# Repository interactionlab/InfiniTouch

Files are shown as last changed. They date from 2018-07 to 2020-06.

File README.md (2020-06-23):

# InfiniTouch: Finger-Aware Interaction on Fully Touch Sensitive Smartphones
This repository contains both the hardware models and specifications for the full-touch smartphone prototype presented in the paper, 
as well as scripts and the model for estimating 3D finger positions on the device as described in the paper. 
Moreover, our dataset can be downloaded in the link provided below.

## Abstract
Smartphones are the most successful mobile devices and offer intuitive interaction through touchscreens. Current devices
treat all fingers equally and only sense touch contacts on the front of the device. In this paper, we present InfiniTouch,
the first system that enables touch input on the whole device surface and identifies the fingers touching the device without
external sensors while keeping the form factor of a standard smartphone. We first developed a prototype with capacitive
sensors on the front, the back and on three sides. We then conducted a study to train a convolutional neural network that
identifies fingers with an accuracy of 95.78% while estimating their position with a mean absolute error of 0.74cm . We
demonstrate the usefulness of multiple use cases made possible with InfiniTouch, including finger-aware gestures and finger
flexion state as an action modifier.

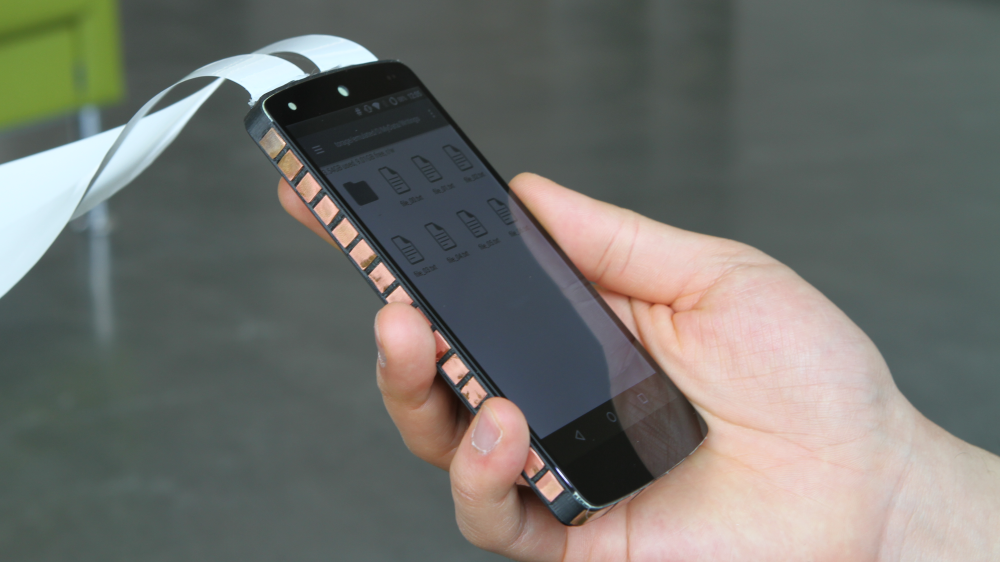
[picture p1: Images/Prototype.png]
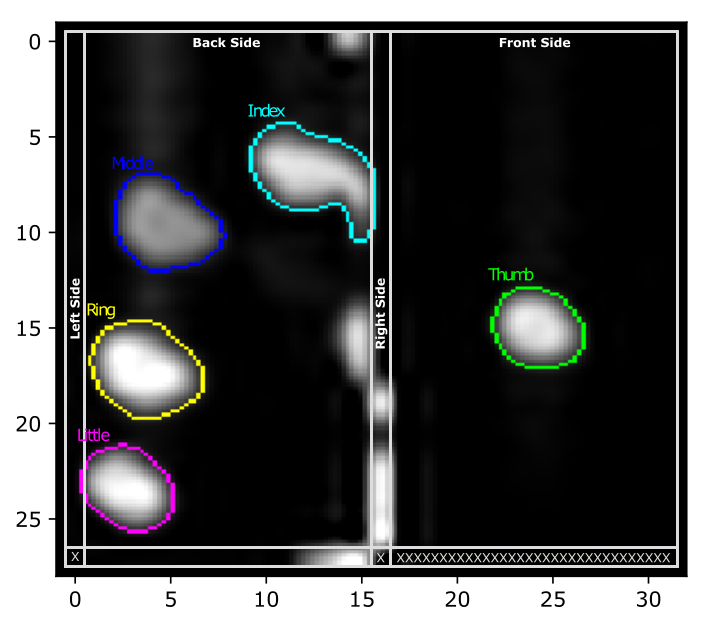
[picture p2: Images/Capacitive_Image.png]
 

This work can be cited as follows:
<pre>
@inproceedings{le2018infinitouch,
 author = {Le, Huy Viet and  Mayer, Sven and Henze, Niels},
 title = {InfiniTouch: Finger-Aware Interaction on Fully Touch Sensitive Smartphones},
 booktitle = {Proceedings of the 31th Annual ACM Symposium on User Interface Software and Technology},
 series = {UIST '18},
 year = {2018},
 isbn = {978-1-4503-5948-1},
 doi = {10.1145/3242587.3242605},
 url = {http://doi.acm.org/10.1145/3242587.3242605},
 location = {Berlin, Germany},
 numpages = {14},
 publisher = {ACM},
 address = {New York, NY, USA}
} 
</pre>

## Dataset
The dataset can be downloaded at: https://www.dropbox.com/s/v8n8uaf5vncusyn/InfiniTouch_Dataset.zip?dl=0. After downloading, place the content of this folder into a folder named 'data'. Place the 'data' folder into the same directory as the Jupyter notebooks. Run the content of these notebooks to create a HDF5 file with which the model can then be trained.

## Prototype
The datasheets of the components that we used in our prototype can be found in the following list of URLs:
- BM10NB(0.8)-40DS-0.4V(51): https://www.datasheets360.com/part/detail/bm10nb-0-8-40ds-0-4v-51/2579290684464631510/
- BM10B(0.8)-40DP-0.4V(51): https://www.datasheets360.com/part/detail/bm10b-0-8-40dp-0-4v-51/-1995328425388918022/
- MPR121QR2: https://www.datasheets360.com/part/detail/mpr121qr2/3714073967749496703/
- MicroUSB Breakout Board: https://cdn-shop.adafruit.com/datasheets/1833_MicroB_20329.pdf
- Tactile Switch: https://cdn-shop.adafruit.com/datasheets/B3F-1000-Omron.pdf
- FH12-50S-0.5SH(05): https://www.datasheets360.com/part/detail/fh12-50s-0-5sh-05/8224149447061018923/
- PCB board + FFC cable: http://diy.shops.hypeltd.com/DIY2//product_info.php?products_id=67

We printed the PCB and placed the components on the board with the service of http://beta-layout.com.

## Android Library
To use the library, include libftsp.jar in your Android project. The capacitive images for the local device can be accessed as follows:
```java
LocalDeviceHandler localDeviceHandler = new LocalDeviceHandler();
localDeviceHandler.setLocalCapImgListener(new LocalCapImgListener() {
    @Override
    public void onLocalCapImg(CapacitiveImageTS capImg) { // called approximately every 50ms
        int[][] matrix = capImg.getMatrix(); // get the 27x15 capacitive image
        int[] flattenedMatrix = capImg.getFlattenedMatrix(); // get a flattened 27x15 capacitive image
        long imgTimestamp = capImg.getTimestamp(); // get timestamp of this image
    }
});
localDeviceHandler.startHandler();
```

The following code is for the front unit. It provides the capacitive images of the front device (local) and further the retrieved capacitive imags of the back and the sides. All capacitive images can be retrieved within callbacks:

```java
try {
    frontDeviceHandler = new FrontDeviceHandler(9584);
} catch (SocketException e) {
    e.printStackTrace();
}

frontDeviceHandler.setFtspCapImgListener(new FTSPCapImgListener() {
    @Override
    public void onNewBackCapacitiveImage(CapacitiveImageTS capacitiveImageTS) {
        // backImage = capacitiveImageTS;
    }

    @Override
    public void onNewFrontCapacitiveImage(CapacitiveImageTS capacitiveImageTS) {
        // frontImage = capacitiveImageTS;
    }

    @Override
    public void onNewSideCapacitiveImage(CapacitiveImageSide capacitiveImageSide) {
        // sideImage = capacitiveImageSide;
    }
});
frontDeviceHandler.startHandler(true);
```

The back unit uses the respective code to broadcast the capacitive images to the front unit. A callback handler can also be added if required.
```java
backDeviceHandler = new BackDeviceHandler(Constants.FRONT_IP, 9584);
backDeviceHandler.startHandler(true);
```

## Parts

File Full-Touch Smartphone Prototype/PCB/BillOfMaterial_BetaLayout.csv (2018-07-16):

BILL OF MATERIAL WITH BETA STOCK, GROUPED BY VALUES, AS OF 09.10.2015
Part | Value | Device | Package | Description | Description2 | Qty | Place_YES/NO | Povided_by_customer_YES/NO | Distributor | Ordernumber | Weblink | Remarks_customer | Unit_price | Total_price | REMARKS_BETA | OPTION1 | OPTION2 | OPTION3
C1, C2, C3, C4, C5, C6 | 0.1uF | CAP0603-CAP | 0603-CAP | Capacitor |  | 6 | YES | NO | Mouser | 581-06033C104JAT2A | http://www.mouser.de/ProductDetail/AVX/06033C104JAT2A/?qs=9m8RHjAONzC2EgWOJLFcaw== |  | 0.292 | 1.752
IC1, IC2, IC3 | MPR121 | MPR121V2 | QFN-20-0.4MM-V2 | MPR121 Capacitive Touch Sensor Controller. Variant V2" was created using an image import of the bottom of the IC. It matches metal to metal." |  | 3 | YES | YES | -
JP1, JP2, JP4, JP5 |  | PINHD-1X14 | 1X14 | PIN HEADER |  | 4 | NO | NO | - | - | - |  | - | -
R1, R9, R12 | 75k | RESISTOR0603-RES | 0603-RES | Resistor |  | 3 | YES | NO | Mouser | 603-RT0603FRE0775KL | http://www.mouser.de/ProductDetail/Yageo/RT0603FRE0775KL/?qs=%2ff7pOCXLR5eTzVWqRTYgyA== |  | 0.179 | 0.537
R2, R3, R4, R5, R6, R7, R8, R10, R11 | 10k | RESISTOR0603-RES | 0603-RES | Resistor |  | 9 | YES | NO | Mouser | 652-CRT0603BY1002EAS | http://www.mouser.de/ProductDetail/Bourns/CRT0603-BY-1002EAS/?qs=EvbCu83THBCh1lt9vIhMzA== |  | 0.521 | 4.689
SJ1, SJ2, SJ3 | SOLDERJUMPERTRACE | SOLDERJUMPERTRACE | SJ_2S-TRACE | Solder Jumper |  | 3
U$1, U$2 | AXE640124 | AXE640124 | AXE640124 | Board to Board & Mezzanine Connectors 0.4MM FPC TO BOARD 40P HDR 0.8 HGHT |  | 2 | YES | NO | Mouser | 798-BM10B0840DP04V51 | http://www.mouser.de/ProductDetail/Hirose-Connector/BM10B08-40DP-04V51/?qs=Z1vyy6eg2vSdmIof9pjdvw== |  | 0.952 | 1.904
U$3, U$40PIN-BACK | AXE540127 | AXE540127 | AXE540127 | Board to Board & Mezzanine Connectors 0.4MM FPC TO BOARD 40P RECP 0.8 HGHT |  | 2 | YES | NO | Mouser | 798-BM10NB0840DS4V51 | http://www.mouser.de/ProductDetail/Hirose-Connector/BM10NB08-40DS-04V51/?qs=Z1vyy6eg2vRBhyC2YsdULQ== |  | 1.2 | 2.4
U$4, U$5, U$6, U$7, U$8, U$9, U$10, U$11, U$12, U$13, U$14, U$15, U$25, U$26, U$27, U$28, U$29, U$30, U$31, U$32, U$33, U$34, U$35, U$36, U$37, U$38, U$39, U$40, U$41, U$42, U$43, U$44, U$45, U$46, U$47, U$48, U$49, U$50, U$51 | SINGLE_LÖT_SPOT_K | SINGLE_LÖT_SPOT_K | SINGLE_LÖT_SPOT_K |  |  | 39
X1, X2, X3, X5 | FH12-50S-0.5SH | FH12-50S-0.5SH | FH12-50S-0.5SH | 0.5mm Pitch Connectors For FPC/FFC |  | 4 | YES | NO | Mouser | 798-FH12-50S-0.5SH55 | http://www.mouser.de/ProductDetail/Hirose-Connector/FH12-50S-05SH55/?qs=Ux3WWAnHpjBIQBSw0Cd5Gw== |  | 3.29 | 13.16

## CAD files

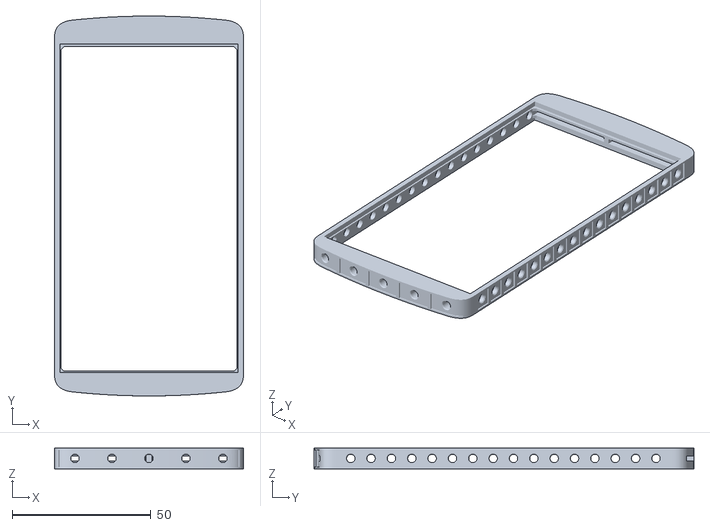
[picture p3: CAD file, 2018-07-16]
Full-Touch Smartphone Prototype/Frame/FullTouchSmartphoneFrame.stl
68.1 x 136.9 x 7.40

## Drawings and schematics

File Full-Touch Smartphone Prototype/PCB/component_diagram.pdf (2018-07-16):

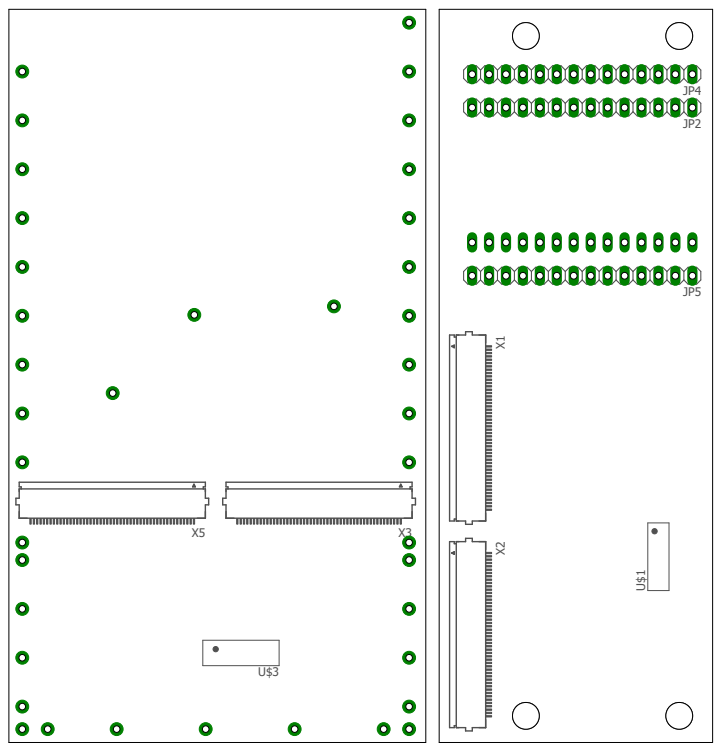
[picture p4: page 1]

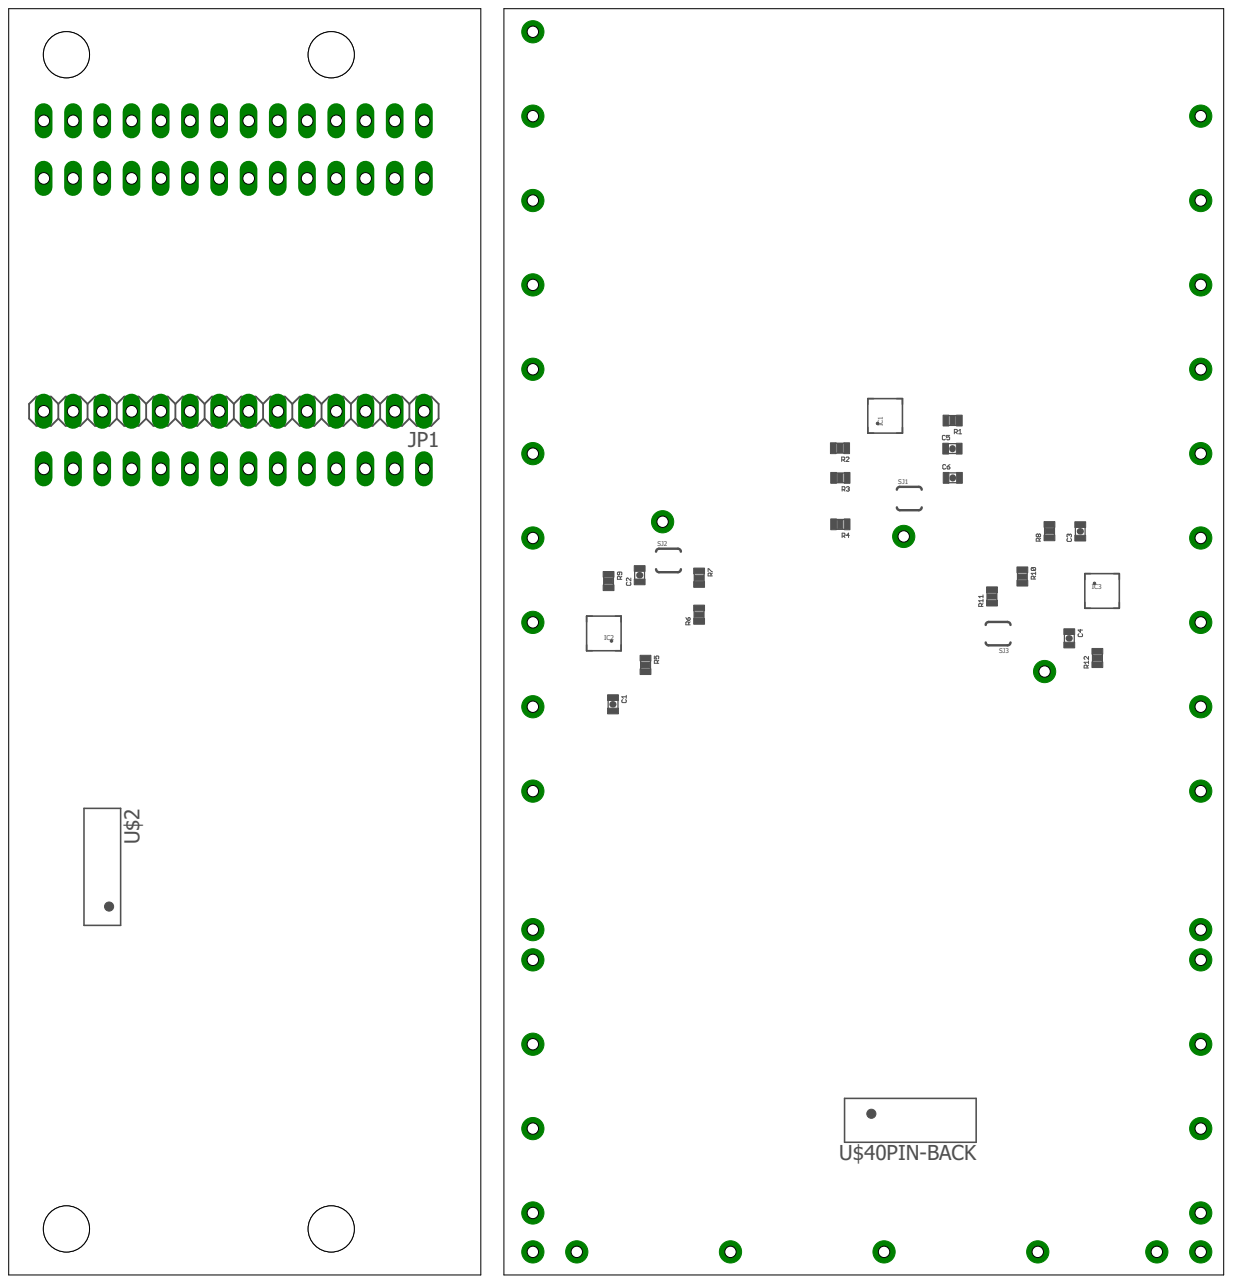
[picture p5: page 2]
U$40PIN-BACK

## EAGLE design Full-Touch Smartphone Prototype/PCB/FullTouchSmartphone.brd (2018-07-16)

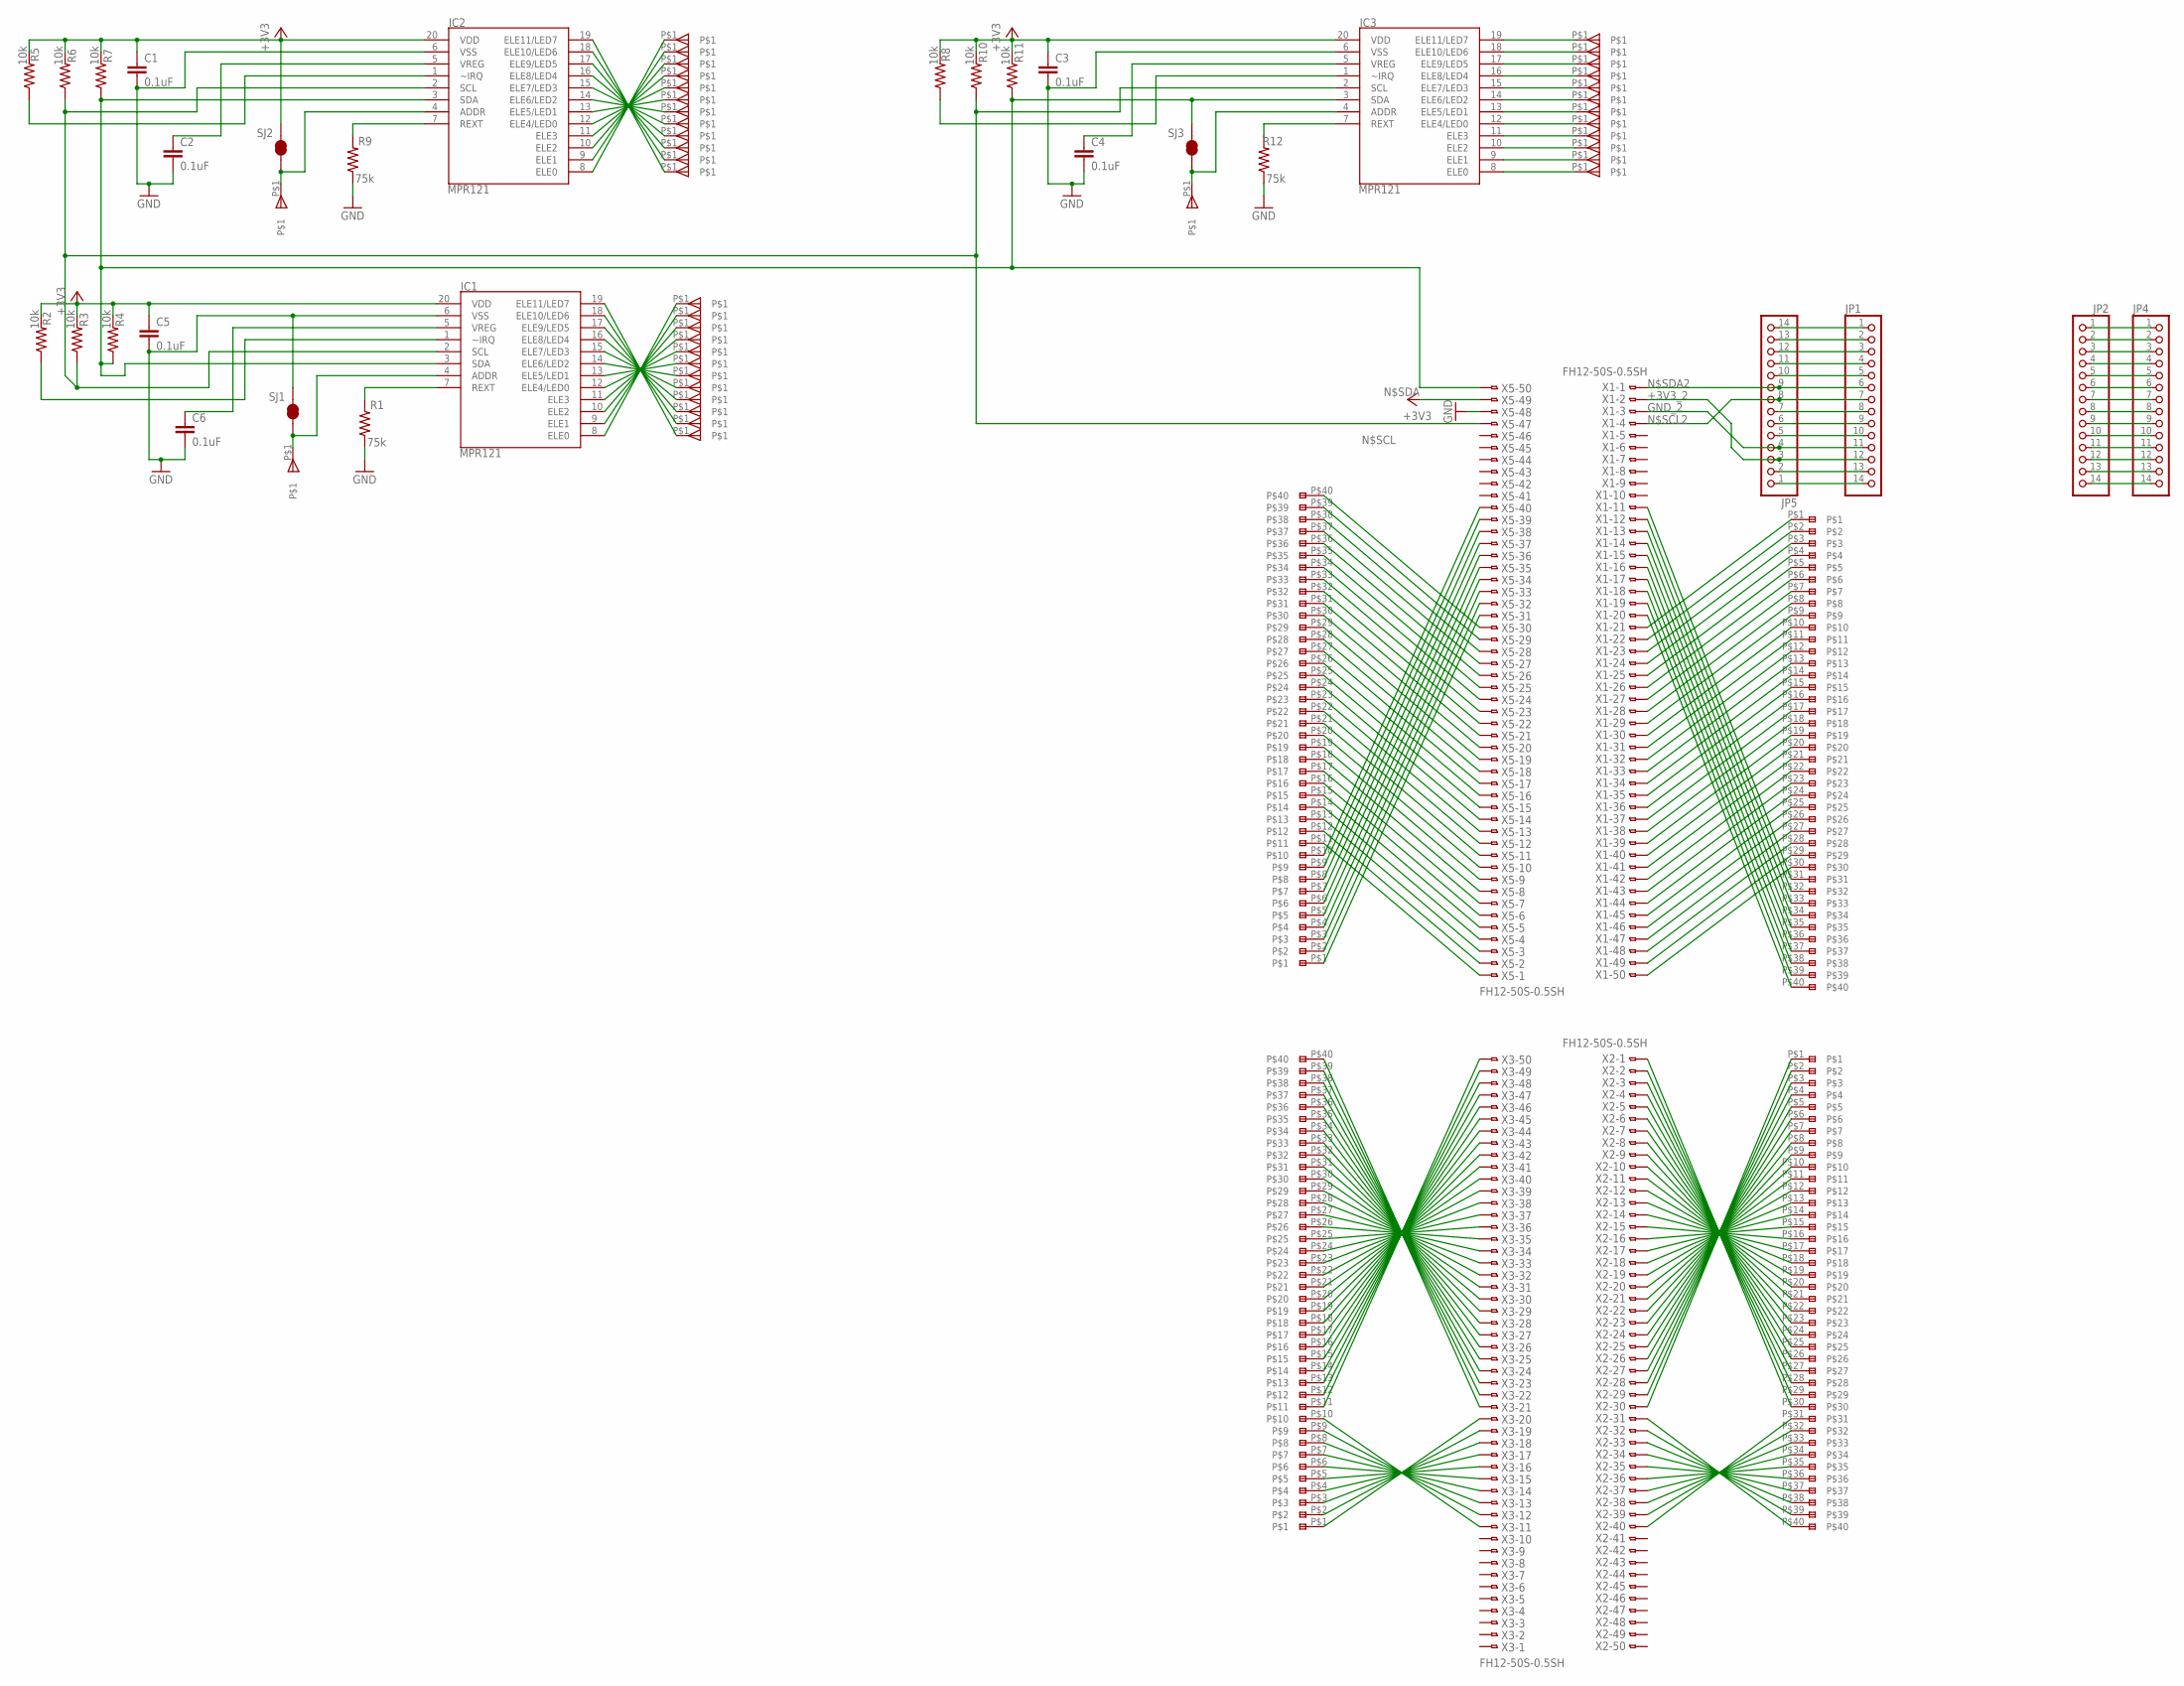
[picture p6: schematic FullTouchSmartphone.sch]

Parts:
C1, C2, C3, C4, C5, C6: 0.1uF; 0603-CAP
IC1, IC2, IC3: MPR121; QFN-20-0.4MM-V2
JP1, JP2, JP4, JP5: PINHD-1X14; 1X14
R1, R9, R12: 75k; 0603-RES
R2, R3, R4, R5, R6, R7, R8, R10, R11: 10k; 0603-RES
SJ1, SJ2, SJ3: SOLDERJUMPERTRACE; SJ_2S-TRACE
U$1, U$2: AXE640124
U$3, U$40PIN-BACK: AXE540127
U$4, U$5, U$6, U$7, U$8, U$9, U$10, U$11, U$12, U$13, U$14, U$15, U$25, U$26, U$27, U$28, U$29, U$30, U$31, U$32, U$33, U$34, U$35, U$36, U$37, U$38, U$39, U$40, U$41, U$42, U$43, U$44, U$45, U$46, U$47, U$48, U$49, U$50, U$51: SINGLE_LÖT_SPOT_K
X1, X2, X3, X5: FH12-50S-0.5SH

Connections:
+3V3: C1.1, C3.1, C5.1, IC1.20 (VDD), IC2.20 (VDD), IC3.20 (VDD), R2.2, R3.2, R4.2, R5.2, R6.2, R7.2, R8.2, R10.2, R11.2, SJ2.2, X5.49
+3V3_2: JP1.12, JP5.3, X1.2
GND: C1.2, C2.2, C3.2, C4.2, C5.2, C6.2, IC1.6 (VSS), IC2.6 (VSS), IC3.6 (VSS), R1.1, R9.1, R12.1, SJ1.2, X5.48
GND_2: JP1.11, JP5.4, X1.3
unnamed: U$40PIN-BACK.P$10, X5.40
unnamed: U$40PIN-BACK.P$9, X5.39
unnamed: U$40PIN-BACK.P$8, X5.38
unnamed: U$40PIN-BACK.P$7, X5.37
unnamed: U$40PIN-BACK.P$6, X5.36
unnamed: U$40PIN-BACK.P$5, X5.35
unnamed: U$40PIN-BACK.P$4, X5.34
unnamed: U$40PIN-BACK.P$3, X5.33
unnamed: U$40PIN-BACK.P$2, X5.32
unnamed: U$40PIN-BACK.P$1, X5.31
unnamed: U$40PIN-BACK.P$20, X5.10
unnamed: U$40PIN-BACK.P$19, X5.9
unnamed: U$40PIN-BACK.P$18, X5.8
unnamed: U$40PIN-BACK.P$17, X5.7
unnamed: U$40PIN-BACK.P$16, X5.6
unnamed: U$40PIN-BACK.P$15, X5.5
unnamed: U$40PIN-BACK.P$14, X5.4
unnamed: U$40PIN-BACK.P$13, X5.3
unnamed: U$40PIN-BACK.P$12, X5.2
unnamed: U$40PIN-BACK.P$11, X5.1
unnamed: U$40PIN-BACK.P$40, X5.30
unnamed: U$40PIN-BACK.P$39, X5.29
unnamed: U$40PIN-BACK.P$38, X5.28
unnamed: U$40PIN-BACK.P$37, X5.27
unnamed: U$40PIN-BACK.P$36, X5.26
unnamed: U$40PIN-BACK.P$35, X5.25
unnamed: U$40PIN-BACK.P$33, X5.23
unnamed: U$40PIN-BACK.P$34, X5.24
unnamed: U$40PIN-BACK.P$32, X5.22
unnamed: U$40PIN-BACK.P$31, X5.21
unnamed: U$40PIN-BACK.P$30, X5.20
unnamed: U$40PIN-BACK.P$29, X5.19
unnamed: U$40PIN-BACK.P$28, X5.18
unnamed: U$40PIN-BACK.P$27, X5.17
unnamed: U$40PIN-BACK.P$26, X5.16
unnamed: U$40PIN-BACK.P$25, X5.15
unnamed: U$40PIN-BACK.P$24, X5.14
unnamed: U$40PIN-BACK.P$23, X5.13
unnamed: U$40PIN-BACK.P$22, X5.12
unnamed: U$40PIN-BACK.P$21, X5.11
unnamed: U$2.P$31, X1.11
unnamed: U$2.P$30, X1.50
unnamed: U$2.P$29, X1.49
unnamed: U$2.P$28, X1.48
unnamed: U$2.P$27, X1.47
unnamed: U$2.P$26, X1.46
unnamed: U$2.P$25, X1.45
unnamed: U$2.P$24, X1.44
unnamed: U$2.P$23, X1.43
unnamed: U$2.P$21, X1.41
unnamed: U$2.P$22, X1.42
unnamed: U$2.P$20, X1.40
unnamed: U$2.P$19, X1.39
unnamed: U$2.P$18, X1.38
unnamed: U$2.P$17, X1.37
unnamed: U$2.P$15, X1.35
unnamed: U$2.P$16, X1.36
unnamed: U$2.P$14, X1.34
unnamed: U$2.P$13, X1.33
unnamed: U$2.P$12, X1.32
unnamed: U$2.P$11, X1.31
unnamed: U$2.P$10, X1.30
unnamed: U$2.P$9, X1.29
unnamed: U$2.P$8, X1.28
unnamed: U$2.P$7, X1.27
unnamed: U$2.P$6, X1.26
unnamed: U$2.P$5, X1.25
unnamed: U$2.P$4, X1.24
unnamed: U$2.P$3, X1.23
unnamed: U$2.P$2, X1.22
unnamed: U$2.P$1, X1.21
unnamed: U$2.P$32, X1.12
unnamed: U$2.P$33, X1.13
unnamed: U$2.P$34, X1.14
unnamed: U$2.P$35, X1.15
unnamed: U$2.P$36, X1.16
unnamed: U$2.P$37, X1.17
unnamed: U$2.P$38, X1.18
unnamed: U$2.P$39, X1.19
unnamed: U$2.P$40, X1.20
unnamed: U$3.P$20, X3.41
unnamed: U$3.P$11, X3.50
unnamed: U$3.P$21, X3.40
unnamed: U$3.P$22, X3.39
unnamed: U$3.P$23, X3.38
unnamed: U$3.P$24, X3.37
unnamed: U$3.P$25, X3.36
unnamed: U$3.P$26, X3.35
unnamed: U$3.P$27, X3.34
unnamed: U$3.P$28, X3.33
unnamed: U$3.P$29, X3.32
unnamed: U$3.P$30, X3.31
unnamed: U$3.P$31, X3.30
unnamed: U$3.P$32, X3.29
unnamed: U$3.P$33, X3.28
unnamed: U$3.P$34, X3.27
unnamed: U$3.P$35, X3.26
unnamed: U$3.P$36, X3.25
unnamed: U$3.P$37, X3.24
unnamed: U$3.P$38, X3.23
unnamed: U$3.P$39, X3.22
unnamed: U$3.P$40, X3.21
unnamed: U$3.P$19, X3.42
unnamed: U$3.P$18, X3.43
unnamed: U$3.P$17, X3.44
unnamed: U$3.P$16, X3.45
unnamed: U$3.P$15, X3.46
unnamed: U$3.P$14, X3.47
unnamed: U$3.P$13, X3.48
unnamed: U$3.P$12, X3.49
unnamed: U$3.P$1, X3.20
unnamed: U$3.P$2, X3.19
unnamed: U$3.P$3, X3.18
unnamed: U$3.P$4, X3.17
unnamed: U$3.P$5, X3.16
unnamed: U$3.P$6, X3.15
unnamed: U$3.P$7, X3.14
unnamed: U$3.P$8, X3.13
unnamed: U$3.P$9, X3.12
unnamed: U$3.P$10, X3.11
unnamed: U$1.P$31, X2.40
unnamed: U$1.P$32, X2.39
unnamed: U$1.P$33, X2.38
unnamed: U$1.P$34, X2.37
unnamed: U$1.P$35, X2.36
unnamed: U$1.P$36, X2.35
unnamed: U$1.P$37, X2.34
unnamed: U$1.P$38, X2.33
unnamed: U$1.P$39, X2.32
unnamed: U$1.P$40, X2.31
unnamed: U$1.P$30, X2.1
unnamed: U$1.P$29, X2.2
unnamed: U$1.P$28, X2.3
unnamed: U$1.P$27, X2.4
unnamed: U$1.P$26, X2.5
unnamed: U$1.P$25, X2.6
unnamed: U$1.P$24, X2.7
unnamed: U$1.P$23, X2.8
unnamed: U$1.P$22, X2.9
unnamed: U$1.P$21, X2.10
unnamed: U$1.P$20, X2.11
unnamed: U$1.P$19, X2.12
unnamed: U$1.P$18, X2.13
unnamed: U$1.P$17, X2.14
unnamed: U$1.P$16, X2.15
unnamed: U$1.P$15, X2.16
unnamed: U$1.P$14, X2.17
unnamed: U$1.P$13, X2.18
unnamed: U$1.P$12, X2.19
unnamed: U$1.P$11, X2.20
unnamed: U$1.P$10, X2.21
unnamed: U$1.P$9, X2.22
unnamed: U$1.P$8, X2.23
unnamed: U$1.P$7, X2.24
unnamed: U$1.P$6, X2.25
unnamed: U$1.P$5, X2.26
unnamed: U$1.P$4, X2.27
unnamed: U$1.P$3, X2.28
unnamed: U$1.P$2, X2.29
unnamed: U$1.P$1, X2.30
unnamed: IC1.19 (ELE11/LED7), U$15.P$1
unnamed: IC1.18 (ELE10/LED6), U$14.P$1
unnamed: IC1.17 (ELE9/LED5), U$13.P$1
unnamed: IC1.16 (ELE8/LED4), U$12.P$1
unnamed: IC1.15 (ELE7/LED3), U$11.P$1
unnamed: IC1.14 (ELE6/LED2), U$10.P$1
unnamed: IC1.13 (ELE5/LED1), U$9.P$1
unnamed: IC1.12 (ELE4/LED0), U$8.P$1
unnamed: IC1.11 (ELE3), U$7.P$1
unnamed: IC1.10 (ELE2), U$6.P$1
unnamed: IC1.9 (ELE1), U$5.P$1
unnamed: IC1.8 (ELE0), U$4.P$1
unnamed: IC3.19 (ELE11/LED7), U$40.P$1
unnamed: IC3.18 (ELE10/LED6), U$41.P$1
unnamed: IC3.17 (ELE9/LED5), U$42.P$1
unnamed: IC3.16 (ELE8/LED4), U$43.P$1
unnamed: IC3.15 (ELE7/LED3), U$44.P$1
unnamed: IC3.14 (ELE6/LED2), U$45.P$1
unnamed: IC3.13 (ELE5/LED1), U$46.P$1
unnamed: IC3.12 (ELE4/LED0), U$47.P$1
unnamed: IC3.10 (ELE2), U$49.P$1
unnamed: IC3.11 (ELE3), U$48.P$1
unnamed: IC3.9 (ELE1), U$50.P$1
unnamed: IC3.8 (ELE0), U$51.P$1
unnamed: JP2.1, JP4.1
unnamed: JP2.2, JP4.2
unnamed: C6.1, IC1.5 (VREG)
unnamed: C2.1, IC2.5 (VREG)
unnamed: IC1.7 (REXT), R1.2
unnamed: IC2.8 (ELE0), U$36.P$1
unnamed: IC2.9 (ELE1), U$35.P$1
unnamed: C4.1, IC3.5 (VREG)
unnamed: IC2.10 (ELE2), U$34.P$1
unnamed: IC2.11 (ELE3), U$33.P$1
unnamed: IC2.12 (ELE4/LED0), U$32.P$1
unnamed: IC2.13 (ELE5/LED1), U$31.P$1
unnamed: IC2.14 (ELE6/LED2), U$30.P$1
unnamed: IC2.15 (ELE7/LED3), U$29.P$1
unnamed: IC2.16 (ELE8/LED4), U$28.P$1
unnamed: IC2.17 (ELE9/LED5), U$27.P$1
unnamed: IC2.18 (ELE10/LED6), U$26.P$1
unnamed: IC2.19 (ELE11/LED7), U$25.P$1
unnamed: IC1.4 (ADDR), SJ1.1, U$37.P$1
unnamed: IC2.7 (REXT), R9.2
unnamed: IC3.7 (REXT), R12.2
unnamed: IC2.4 (ADDR), SJ2.1, U$38.P$1
unnamed: IC3.4 (ADDR), SJ3.1, U$39.P$1
unnamed: JP2.3, JP4.3
unnamed: JP2.4, JP4.4
unnamed: JP2.5, JP4.5
unnamed: JP2.6, JP4.6
unnamed: JP2.7, JP4.7
unnamed: JP2.8, JP4.8
unnamed: JP2.9, JP4.9
unnamed: JP2.10, JP4.10
unnamed: JP2.11, JP4.11
unnamed: JP2.12, JP4.12
unnamed: JP2.13, JP4.13
unnamed: JP2.14, JP4.14
unnamed: JP1.1, JP5.14
unnamed: JP1.2, JP5.13
unnamed: JP1.3, JP5.12
unnamed: JP1.4, JP5.11
unnamed: JP1.5, JP5.10
unnamed: JP1.8, JP5.7
unnamed: JP1.9, JP5.6
unnamed: JP1.10, JP5.5
unnamed: JP1.13, JP5.2
unnamed: JP1.14, JP5.1
N$IRQ1: IC1.1 (~IRQ), R2.1
N$IRQ2: IC2.1 (~IRQ), R5.1
N$IRQ3: IC3.1 (~IRQ), R8.1
N$SCL: IC1.2 (SCL), IC2.2 (SCL), IC3.2 (SCL), R3.1, R6.1, R10.1, X5.47
N$SCL2: JP1.7, JP5.8, X1.4
N$SDA: IC1.3 (SDA), IC2.3 (SDA), IC3.3 (SDA), R4.1, R7.1, R11.1, SJ3.2, X5.50
N$SDA2: JP1.6, JP5.9, X1.1

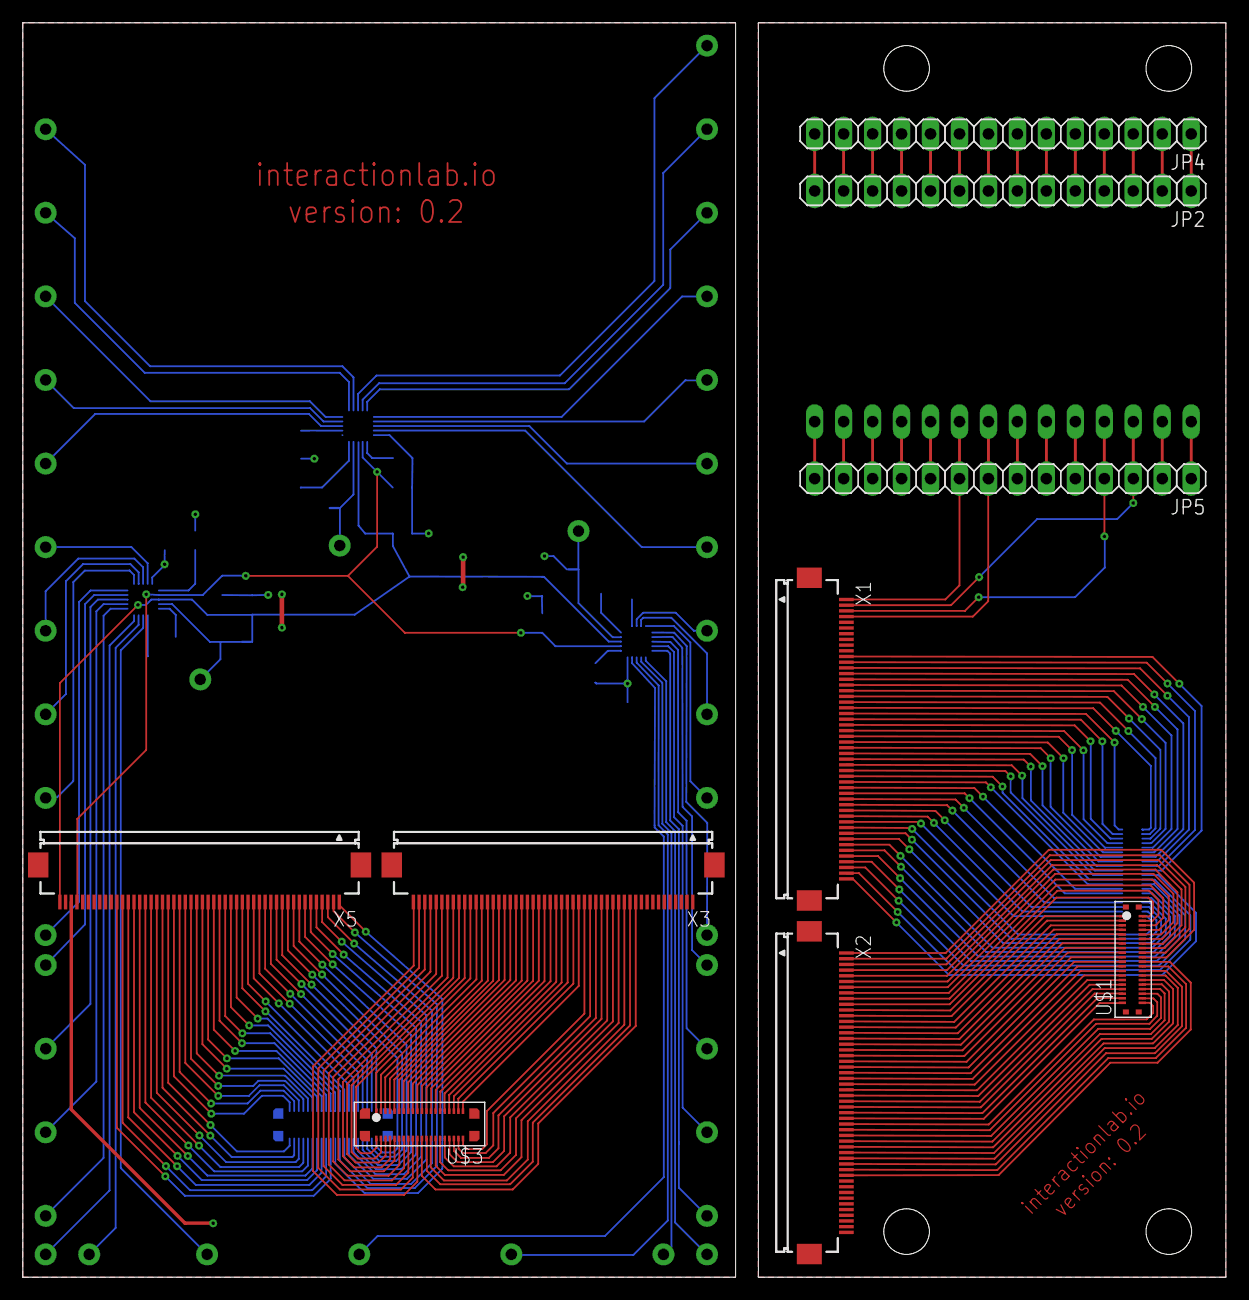
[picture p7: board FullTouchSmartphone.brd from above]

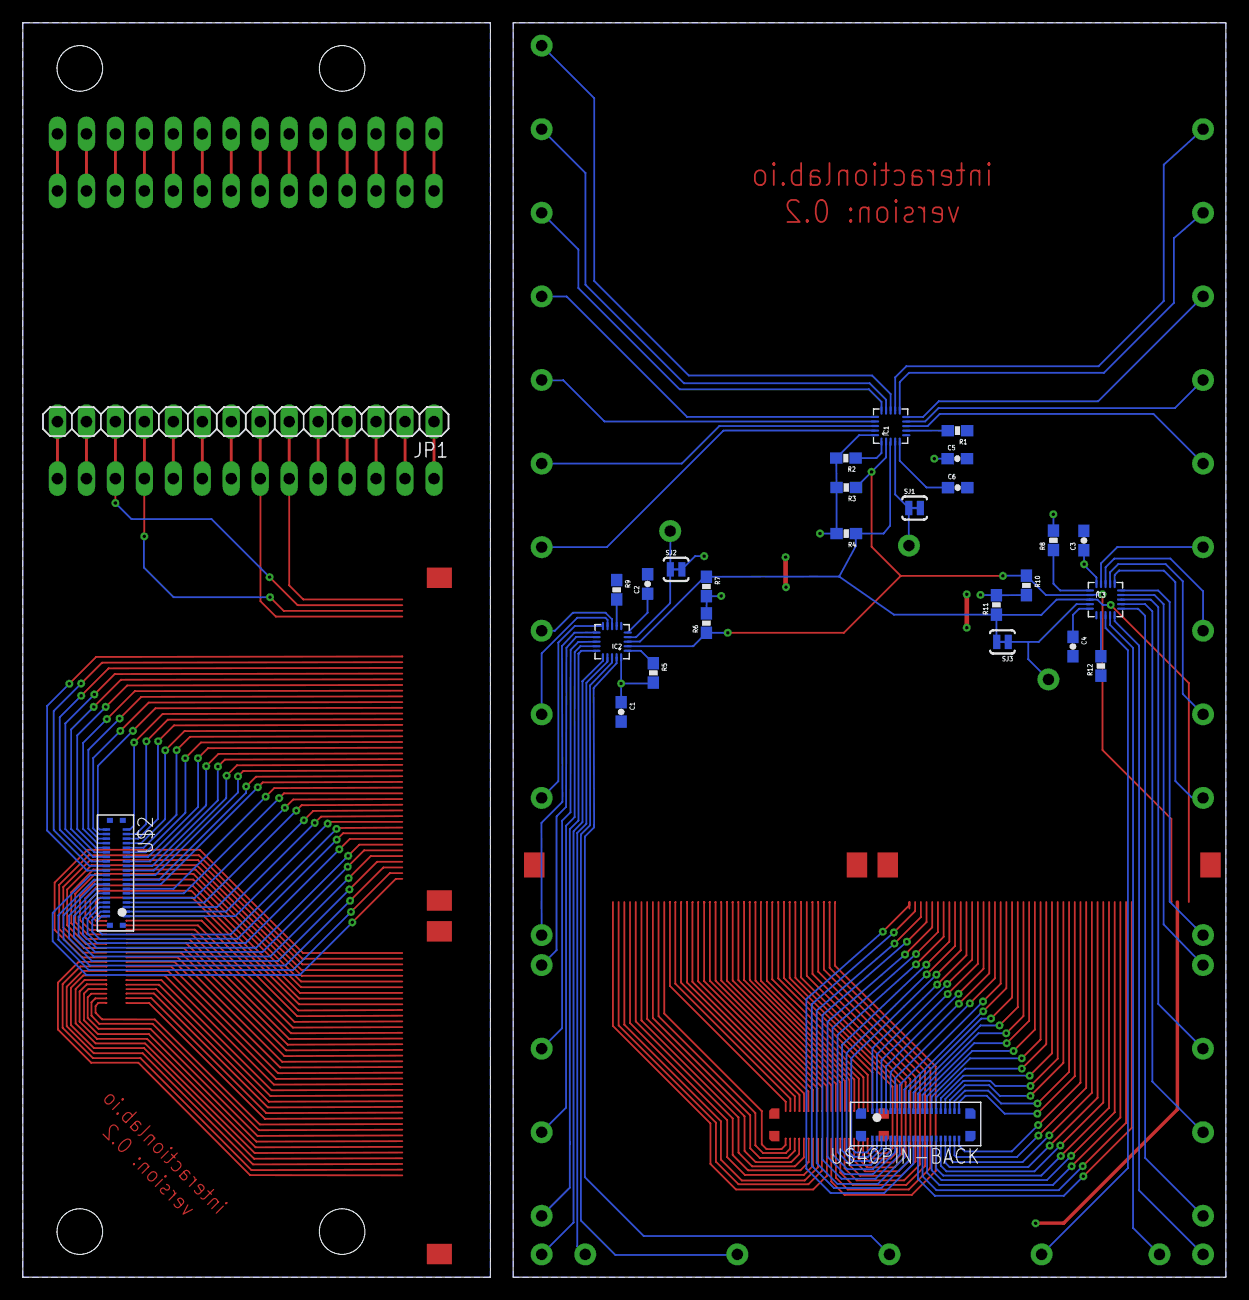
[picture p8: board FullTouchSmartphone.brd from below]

Board: 2 copper layers, 105.5 x 110.0 mm, 75 parts (27 on the bottom side), 240 nets.

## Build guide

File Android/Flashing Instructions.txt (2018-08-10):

- This kernel is only for the LG Nexus 5 (hammerhead)
- Flash TWRP using fastboot first 
- Then use TWRP to flash the kernel. Instructions: https://twrp.me/lg/lgnexus5.html

Capacitive images are written to /proc/capacitive_matrix. You can use libftsp.jar as described in the README.MD to access the capacitive images in your own Android application.

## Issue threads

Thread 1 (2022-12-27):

How to build kernel for other devices?

QueueRear, 2022-12-27:
I've read the instruction of [ACCESSING RAW CAPACITIVE IMAGES ON COMMODITY SMARTPHONES](http://huyle.de/blog/capacitive-images/), where it's mentioned that a modified kernel is required but compiling a whole Android kernel is time-comsuming thus a compiled kernel is provided in this repository.

The tutorial is quite helpful, but I wonder how to apply it to other Android devices equipped with Synaptics touchscreens. I can find a proper modified kernel, but how can I only compile the needed part of the kernel instead of an entire one to a flashable zip file?

I'll be greatly grateful if you can give me any help.

sven-mayer, 2022-12-27:
@QueueRear, the kernel must be compiled per device as they are device and even Android version specific. Thus, you need to build the whole OS to get the kernel needed for your specific device.

If you have a kernel, you can copy the kernel in via "adb shell" no need to flash the whole Android via ZIP file; however, you need to acquire root rights first.

QueueRear, 2023-01-14:
Thx for your detailed reply greatly! It helps a lot and I've modified my device successfully.

Closed 2023-01-14.

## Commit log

2018-07-16 Added first batch of files.
    [FullTouchSmartphone.brd, FullTouchSmartphone.sch, FullTouchSmartphoneFrame.stl]
2018-07-16 Added BillOfMaterial and Component Layout (can be re-used for Beta Layout)
    [BillOfMaterial_BetaLayout.csv]
2018-08-10 Added modified kernel for the Nexus 5 which provides the capacitive images.
